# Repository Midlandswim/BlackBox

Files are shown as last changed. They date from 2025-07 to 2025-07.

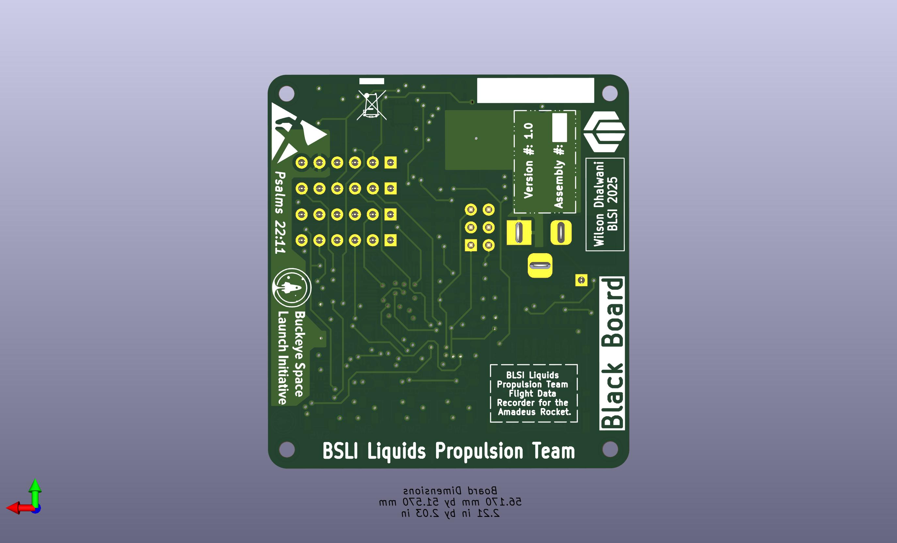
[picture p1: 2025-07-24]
Media/BlackBoxBLSIPCBBack.jpg

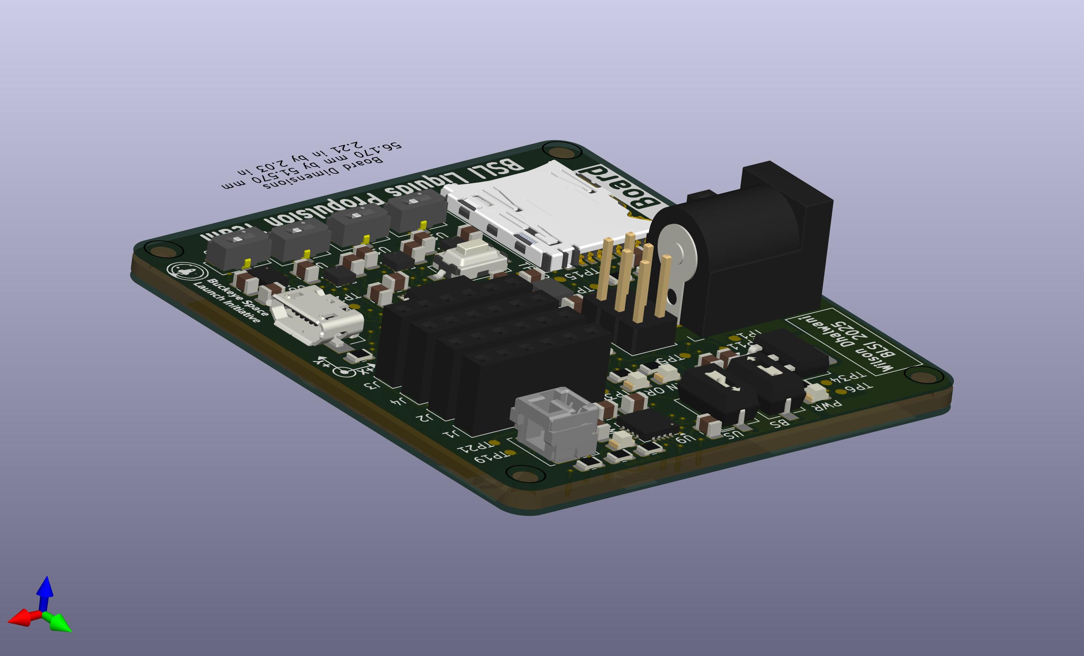
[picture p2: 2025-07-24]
Media/BlackBoxBLSIPCBSidejpg.jpg

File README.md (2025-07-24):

# BlackBox
BlackBox Flight Data Recorder

This is in partnership with Dhalwani Designs, which holds all rights, data, and procedures for this project and the related. This project was made for the Buckeye Space Launch Initiative Liquids Research Team. <br />

Researcher: Wilson Dhalwani <br />
Aides: Mr. Julian Hooks (OSU) <br />
Context: Dhalwani Designs Sanctioned Project and BSLI Liquids Project <br />
Project Name: The Blackbox <br />
Start Date: January 09, 2025 <br /> 

The following repository is for documenting and sharing my work in this research and competition project and its related fields of electrical and avionics engineering. This was also made to record my process of solving the issue at hand so that others can learn and build upon my work. Wanting to advance my experience and skills in avionics, as well as PCB design, I sought to join the Buckeye Space Launch Initiative, and specifically the Liquids Project Team (https://www.bsli.space/projects/liquids/). I quickly grasped concepts and joined the electronics/avionics subteam. Working closely with Mr. Julian Hooks, I have gained great experience, expertise, and knowledge in the field and its accompanying areas of study/research. Mr. Hooks has been an amazing team lead, mentor, and friend, and I hope to grow into half the leader and engineer he is. I was quickly assigned the task of creating the dedicated and versatile flight data recorder for the entire system of our up and coming rocket. For some context, this rocket will be a high powered rocket that aims to break the current collegiete apogee record. All custom designed, built, and manufactured, this rocket is composed of comepletly novel and innovative approaches to existing technology to advance the capabilities of the field but to also promote increased investment/interest into the related fields. Getting back to my individual role and contributions, I solely worked on the research, design, and development of this board, ensuring this critical component of the entire electronic as well as non-electronic systems would not only do its duty as our last resort, but still aid in achieving the overarching goals. One may notice key design choices throughout this board, as well as its expansive (and further expandable) capabilities. Ranging from dedicated and secure communication lines to extremely sensitive sensors, the BlackBox, as I have named it, will be a reliable yet hopefully unused aspect of this rocket. Aside from the more standard features such as event/data recording and reliable dedicated power systems, the processing and versatility of this system have been unmatched thus far (as compared to similar models in the collegeite field). A specialized enclosure was also designed to aid in protecting the board while also maximizing utility and accessibility during the implementation phase. This project has no end date as an innovation never ends, rather, continues until the idea is forgotten, and my hope is that this work can be the basis for future engineers who, too, find great excitement in innovation and design. <br />

Should you have any questions, comments, or just wish to reach out, email me at wilson.dhalwani@gmail.com !

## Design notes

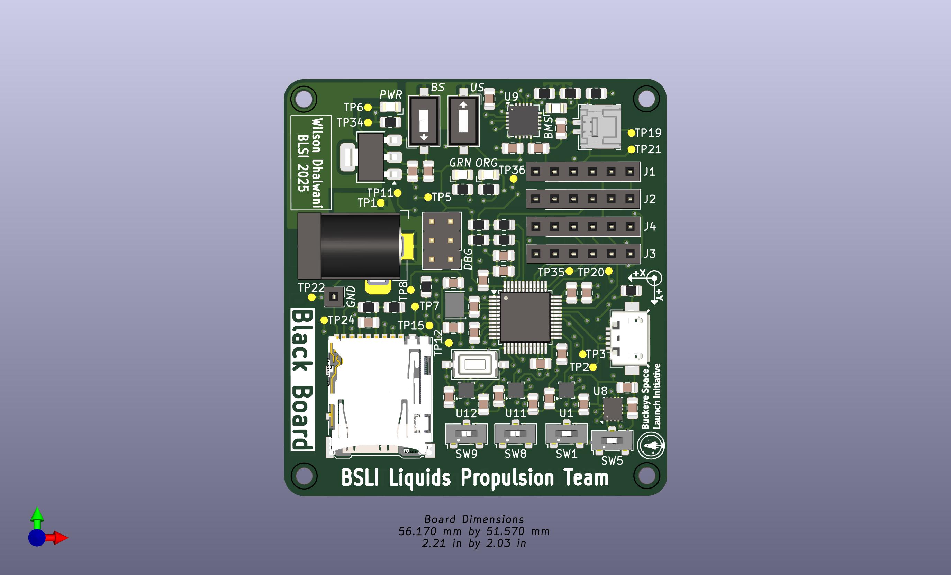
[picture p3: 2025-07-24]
Media/BlackBoxBLSIPCBFront.jpg

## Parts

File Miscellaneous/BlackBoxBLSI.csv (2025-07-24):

Id | Designator | Footprint | Quantity | Designation | Supplier and ref
1 | Y1 | Oscillator_SMD_EuroQuartz_XO32-4Pin_3.2x2.5mm | 1 | Crystal 32.768 kHz
2 | U8 | Bosch_LGA-14_3x2.5mm_P0.5mm | 1 | BMI323
3 | C35,C7,C6,C11,C10,C34,C42,C36,C8,C9 | C_0805_2012Metric | 10 | 100 nF
4 | TP5,TP34,TP12,TP6,TP11,TP7,TP36,TP8,TP20,TP22,TP35,TP24,TP2,TP1,TP21,TP19,TP15,TP3 | TestPoint_Pad_D1.0mm | 18 | TestPoint
5 | C13,C14 | C_0805_2012Metric | 2 | 0.1 uF
6 | PWR | LED_0805_2012Metric | 1 | BLULED
7 | U12,U1,U11 | ST_HLGA-10_2x2mm_P0.5mm_LayoutBorder3x2y | 3 | BMP390
8 | R19 | R_0805_2012Metric | 1 | 270 Ω
9 | C45,C43,C2,C46,C44,C1 | C_0805_2012Metric | 6 | 100nF
10 | H1,H2,H3,H4 | MountingHole_2.2mm_M2_ISO7380 | 4 | MountingHole_Pad
11 | SW5,SW1,SW8,SW9 | Nidec_Copal_CAS-120A | 4 | SW_SPDT
12 | U10 | SOT-223 | 1 | AMS1117-3.3
13 | LEDRES2,LEDRES1 | R_0805_2012Metric | 2 | 270Ω
14 | C5,C12,C41,C40,C37 | C_0805_2012Metric | 5 | 10 uF
15 | BS,US | SW_DIP_SPSTx01_Slide_6.7x4.1mm_W6.73mm_P2.54mm_LowProfile_JPin | 2 | SW_SPST
16 | C38,C39 | C_0805_2012Metric | 2 | 22 uF
17 | U9 | LFCSP-20-1EP_4x4mm_P0.5mm_EP2.6x2.6mm | 1 | ADP5063
18 | R7,R6 | R_0805_2012Metric | 2 | 4.7kΩ
19 | J1,J4,J2,J3 | PinSocket_1x06_P2.54mm_Vertical | 4 | Conn_01x06_Pin
20 | R20,R18 | R_0805_2012Metric | 2 | 10 kΩ
21 | GND | PinSocket_1x01_P2.54mm_Vertical | 1 | Conn_01x01_Pin
22 | R22,R23 | R_0805_2012Metric | 2 | 10k
23 | R9,R8 | R_0805_2012Metric | 2 | 1Ω
24 | J6 | BarrelJack_Horizontal | 1 | Barrel_Jack
25 | RSTCAP1 | R_0805_2012Metric | 1 | 0.1uF
26 | R21 | R_0805_2012Metric | 1 | 10kΩ
27 | C15 | C_0805_2012Metric | 1 | 3 pF
28 | BT1 | Molex_CLIK-Mate_502382-0270_1x02-1MP_P1.25mm_Vertical | 1 | 4.2V Batt
29 | BMS | LED_0805_2012Metric | 1 | REDLED
30 | J8 | USB_Micro-B_Amphenol_10104110_Horizontal | 1 | USB_B_Micro
31 | LEDRES3 | R_0805_2012Metric | 1 | 75Ω
32 | SW6 | SW_Tactile_SPST_NO_Straight_CK_PTS636Sx25SMTRLFS | 1 | SW_Push
33 | GRN | LED_0805_2012Metric | 1 | GREENLED
34 | J9 | microSD_HC_Hirose_DM3AT-SF-PEJM5 | 1 | Micro_SD_Card
35 | DBG | PinHeader_2x03_P2.54mm_Vertical | 1 | Conn_02x03_Counter_Clockwise
36 | U3 | LQFP-48_7x7mm_P0.5mm | 1 | STM32U575CIT6
37 | ORG | LED_0805_2012Metric | 1 | ORNGELED

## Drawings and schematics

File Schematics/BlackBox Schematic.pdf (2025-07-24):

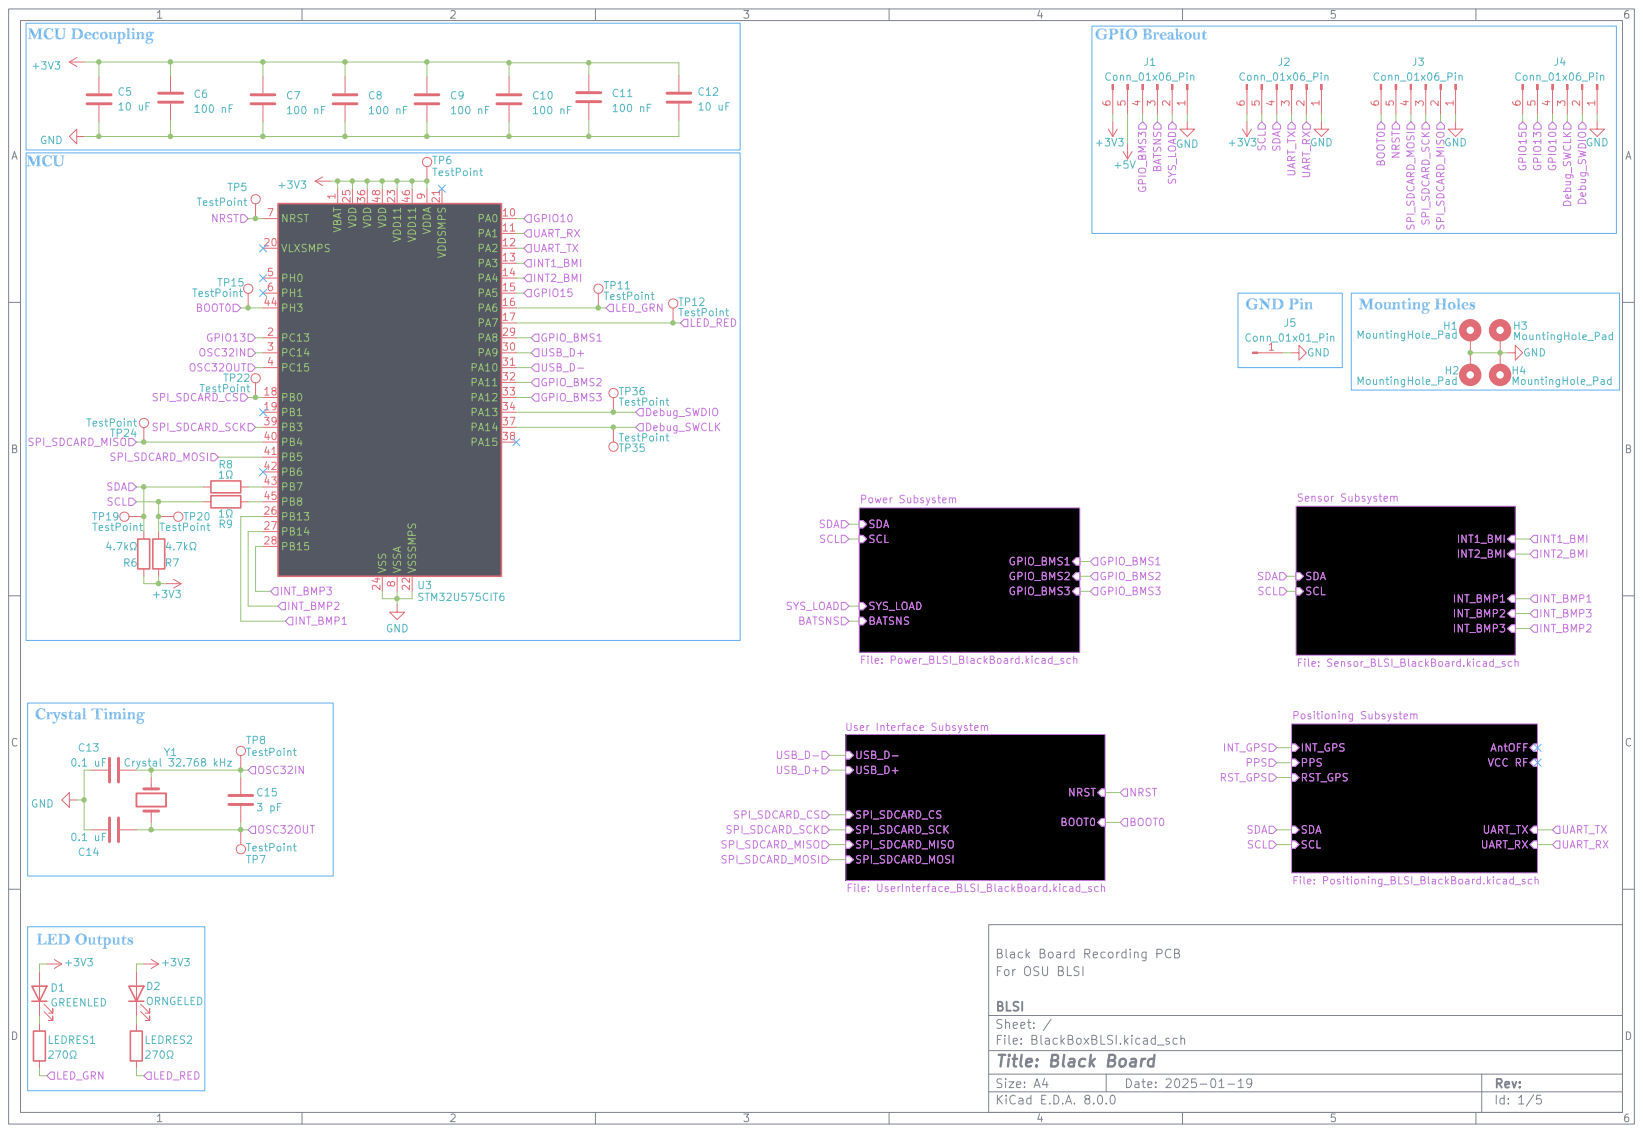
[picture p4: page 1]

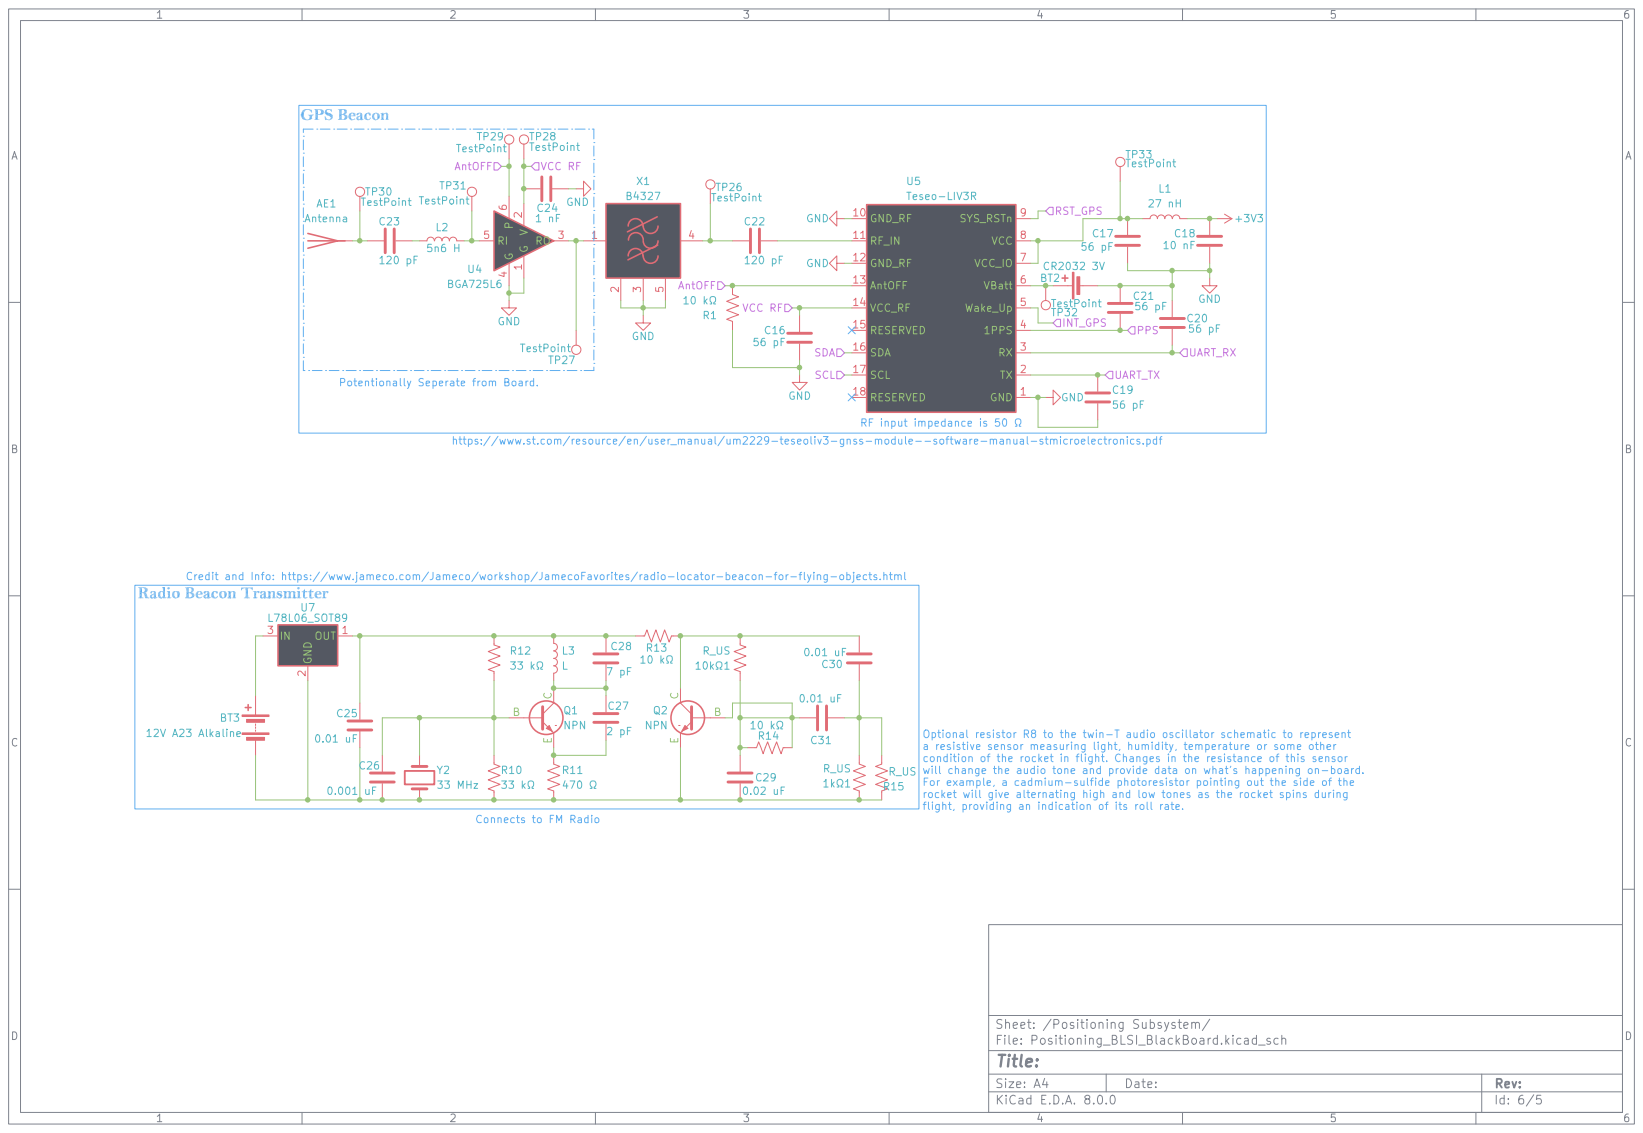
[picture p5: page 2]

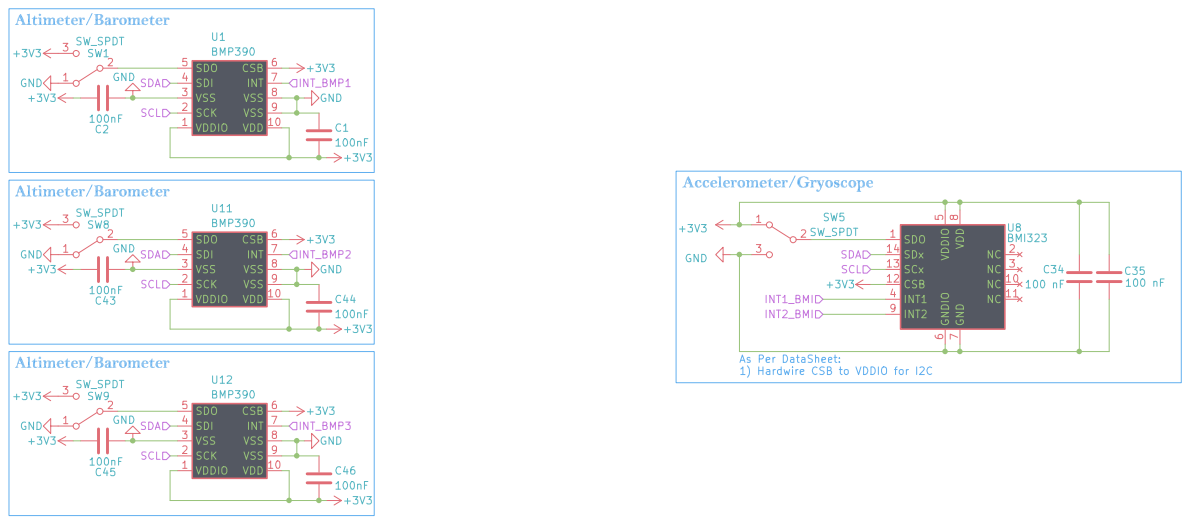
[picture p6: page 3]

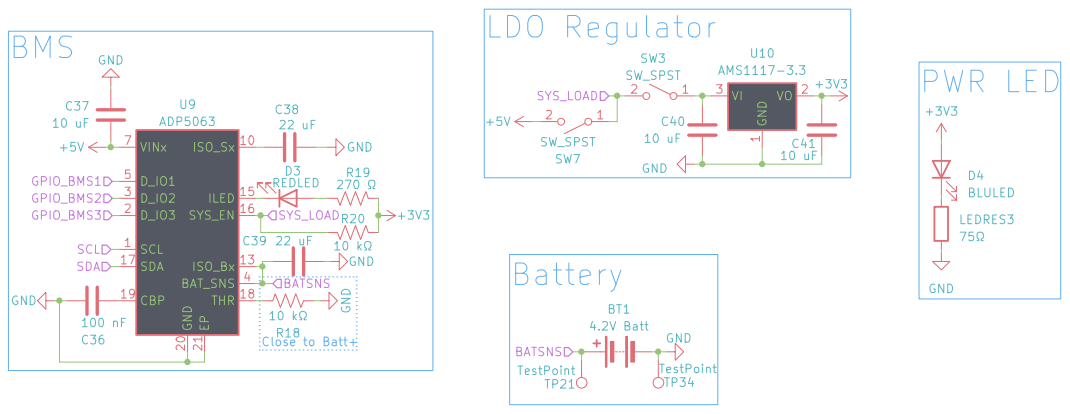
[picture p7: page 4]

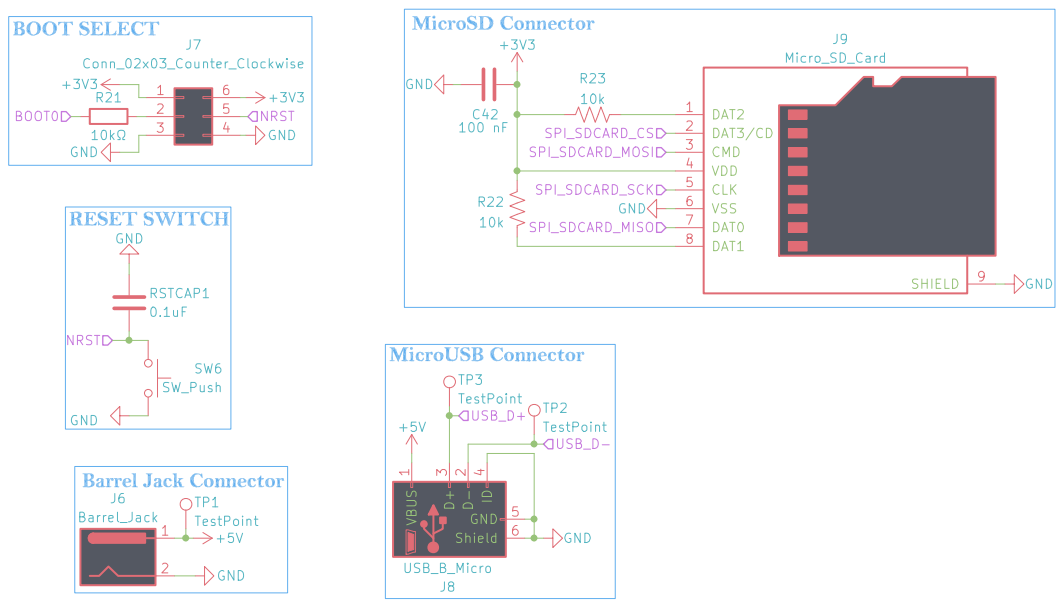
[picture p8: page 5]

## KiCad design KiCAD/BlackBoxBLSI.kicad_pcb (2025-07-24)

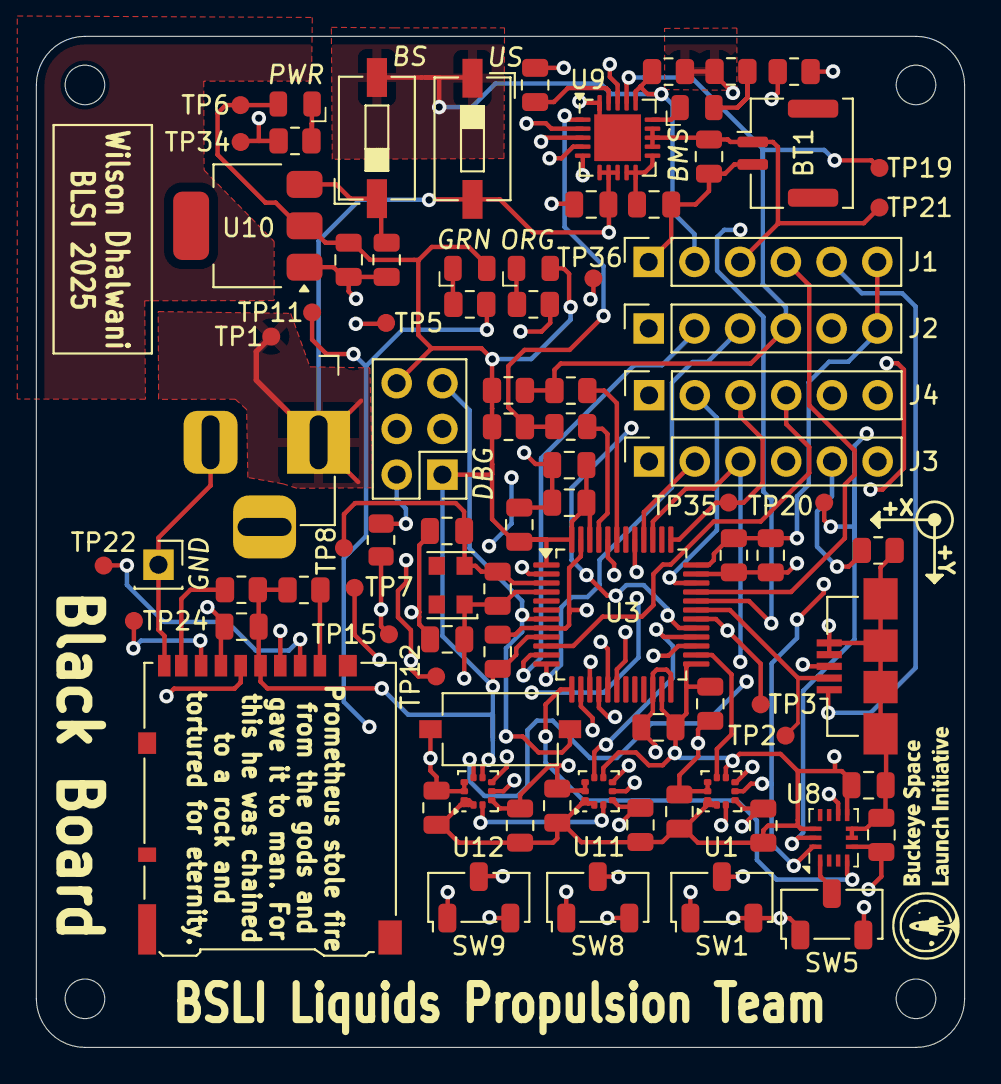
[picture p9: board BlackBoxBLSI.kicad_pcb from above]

Board: 4 copper layers, 51.6 x 56.2 mm, 91 parts (0 on the bottom side), 52 nets.

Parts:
BMS: REDLED; LED_0805_2012Metric
BS: SW_SPST; SW_DIP_SPSTx01_Slide_6.7x4.1mm_W6.73mm_P2.54mm_LowProfile_J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
BT1: 4.2V Batt; Molex_CLIK-Mate_502382-0270_1x02-1MP_P1.25mm_Vertical
C1, C2, C43, C44, C45, C46: 100nF; C_0805_2012Metric
C5, C12, C37, C40, C41: 10 uF; C_0805_2012Metric
C6, C7, C8, C9, C10, C11, C34, C35, C36, C42: 100 nF; C_0805_2012Metric
C13, C14: 0.1 uF; C_0805_2012Metric
C15: 3 pF; C_0805_2012Metric
C38, C39: 22 uF; C_0805_2012Metric
DBG: Conn_02x03_Counter_Clockwise; PinHeader_2x03_P2.54mm_Vertical
GND: Conn_01x01_Pin; PinSocket_1x01_P2.54mm_Vertical
GRN: GREENLED; LED_0805_2012Metric
H1, H2, H3, H4: MountingHole_Pad; MountingHole_2.2mm_M2_ISO7380
J1, J2, J3, J4: Conn_01x06_Pin; PinSocket_1x06_P2.54mm_Vertical
J6: Barrel_Jack; BarrelJack_Horizontal
J8: USB_B_Micro; USB_Micro-B_Amphenol_10104110_Horizontal
J9: Micro_SD_Card; microSD_HC_Hirose_DM3AT-SF-PEJM5
LEDRES1, LEDRES2: 270Ω; R_0805_2012Metric
LEDRES3: 75Ω; R_0805_2012Metric
ORG: ORNGELED; LED_0805_2012Metric
PWR: BLULED; LED_0805_2012Metric
R6, R7: 4.7kΩ; R_0805_2012Metric
R8, R9: 1Ω; R_0805_2012Metric
R18, R20: 10 kΩ; R_0805_2012Metric
R19: 270 Ω; R_0805_2012Metric
R21: 10kΩ; R_0805_2012Metric
R22, R23: 10k; R_0805_2012Metric
RSTCAP1: 0.1uF; R_0805_2012Metric
SW1, SW5, SW8, SW9: SW_SPDT; Nidec_Copal_CAS-120A
SW6: SW_Push; SW_Tactile_SPST_NO_Straight_CK_PTS636Sx25SMTRLFS
TP1, TP2, TP3, TP5, TP6, TP7, TP8, TP11, TP12, TP15, TP19, TP20, TP21, TP22, TP24, TP34, TP35, TP36: TestPoint; TestPoint_Pad_D1.0mm
U1, U11, U12: BMP390; ST_HLGA-10_2x2mm_P0.5mm_LayoutBorder3x2y
U3: STM32U575CIT6; LQFP-48_7x7mm_P0.5mm
U8: BMI323; Bosch_LGA-14_3x2.5mm_P0.5mm
U9: ADP5063; LFCSP-20-1EP_4x4mm_P0.5mm_EP2.6x2.6mm
U10: AMS1117-3.3; SOT-223
US: SW_SPST; SW_DIP_SPSTx01_Slide_6.7x4.1mm_W6.73mm_P2.54mm_LowProfile_J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
Y1: Crystal 32.768 kHz; Oscillator_SMD_EuroQuartz_XO32-4Pin_3.2x2.5mm

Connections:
+3V3: C1.2, C2.1, C5.1, C6.1, C7.1, C8.1, C9.1, C10.1, C11.1, C12.1, C34.1, C35.1, C41.1, C42.2, C43.1, C44.2, C45.1, C46.2, DBG.1, DBG.6, GRN.2 (A), J1.6, J2.6, J9.4 (VDD), ORG.2 (A), PWR.2 (A), R6.1, R7.2, R19.2, R20.2, R22.1, R23.1, SW1.3 (C), SW5.1 (A), SW8.3 (C), SW9.3 (C), TP6.1, U1.1 (VDDIO), U1.6 (CSB), U1.10 (VDD), U3.1 (VBAT), U3.9 (VDDA), U3.23 (VDD11), U3.25 (VDD), U3.36 (VDD), U3.46 (VDD11), U3.48 (VDD), U8.5 (VDDIO), U8.8 (VDD), U8.12 (CSB), U10.2 (VO), U11.1 (VDDIO), U11.6 (CSB), U11.10 (VDD), U12.1 (VDDIO), U12.6 (CSB), U12.10 (VDD)
+5V: C37.2, J1.5, J6.1, J8.1 (VBUS), TP1.1, U9.6 (VINx), U9.7 (VINx), U9.8 (VINx), US.2 (B)
/BATSNS: BT1.1 (+), C39.2, J1.3, TP21.1, U9.4 (BAT_SNS), U9.12 (ISO_Bx), U9.13 (ISO_Bx), U9.14 (ISO_Bx)
/BOOT0: J3.6, R21.2, TP15.1, U3.44 (PH3)
/Debug_SWCLK: J4.3, TP35.1, U3.37 (PA14)
/Debug_SWDIO: J4.2, TP36.1, U3.34 (PA13)
/GPIO10: J4.4, U3.10 (PA0)
/GPIO13: J4.5, U3.2 (PC13)
/GPIO15: J4.6, U3.15 (PA5)
/GPIO_BMS1: U3.29 (PA8), U9.5 (D_IO1)
/GPIO_BMS2: U3.32 (PA11), U9.3 (D_IO2)
/GPIO_BMS3: J1.4, U3.33 (PA12), U9.2 (D_IO3)
/INT1_BMI: U3.13 (PA3), U8.4 (INT1)
/INT2_BMI: U3.14 (PA4), U8.9 (INT2)
/INT_BMP1: U1.7 (INT), U3.26 (PB13)
/INT_BMP2: U3.27 (PB14), U12.7 (INT)
/INT_BMP3: U3.28 (PB15), U11.7 (INT)
/LED_GRN: LEDRES1.2, TP11.1, U3.16 (PA6)
/LED_RED: LEDRES2.2, TP12.1, U3.17 (PA7)
/NRST: DBG.5, J3.5, RSTCAP1.2, SW6.1, TP5.1, U3.7 (NRST)
/OSC32IN: C13.1, C15.1, TP8.1, U3.3 (PC14), Y1.2
/OSC32OUT: C14.2, C15.2, TP7.1, U3.4 (PC15), Y1.1
/SCL: J2.5, R7.1, R9.1, TP20.1, U1.2 (SCK), U8.13 (SCx), U9.1 (SCL), U11.2 (SCK), U12.2 (SCK)
/SDA: J2.4, R6.2, R8.1, TP19.1, U1.4 (SDI), U8.14 (SDx), U9.17 (SDA), U11.4 (SDI), U12.4 (SDI)
/SPI_SDCARD_CS: J9.2 (DAT3/CD), TP22.1, U3.18 (PB0)
/SPI_SDCARD_MISO: J3.2, J9.7 (DAT0), TP24.1, U3.40 (PB4)
/SPI_SDCARD_MOSI: J3.4, J9.3 (CMD), U3.41 (PB5)
/SPI_SDCARD_SCK: J3.3, J9.5 (CLK), U3.39 (PB3)
/SYS_LOAD: BS.2 (B), J1.2, R20.1, U9.16 (SYS_EN), US.1 (A)
/UART_RX: J2.2, U3.11 (PA1)
/UART_TX: J2.3, U3.12 (PA2)
/USB_D+: J8.3 (D+), TP3.1, U3.30 (PA9)
/USB_D-: J8.2 (D-), TP2.1, U3.31 (PA10)
GND: BT1.2 (-), C1.1, C2.2, C5.2, C6.2, C7.2, C8.2, C9.2, C10.2, C11.2, C12.2, C13.2, C14.1, C34.2, C35.2, C36.1, C37.1, C38.1, C39.1, C40.2, C41.2, C42.1, C43.2, C44.1, C45.2, C46.1, DBG.3, DBG.4, GND.1, J1.1, J2.1, J3.1, J4.1, J6.2, J8.4 (ID), J8.5 (GND), J8.6 (Shield), J9.6 (VSS), J9.9 (SHIELD), LEDRES3.2, R18.2, RSTCAP1.1, SW1.1 (A), SW5.3 (C), SW6.2, SW8.1 (A), SW9.1 (A), TP34.1, U1.3 (VSS), U1.8 (VSS), U1.9 (VSS), U3.8 (VSSA), U3.22 (VSSSMPS), U3.24 (VSS), U3.35 (VSS), U3.47 (VSS), U8.6 (GNDIO), U8.7 (GND), U9.20 (GND), U9.21 (EP), U10.1 (GND), U11.3 (VSS), U11.8 (VSS), U11.9 (VSS), U12.3 (VSS), U12.8 (VSS), U12.9 (VSS)
unnamed: C38.2, U9.9 (ISO_Sx), U9.10 (ISO_Sx), U9.11 (ISO_Sx)
unnamed: GRN.1 (K), LEDRES1.1
unnamed: LEDRES2.1, ORG.1 (K)
unnamed: BMS.2 (A), R19.1
unnamed: BMS.1 (K), U9.15 (ILED)
unnamed: LEDRES3.1, PWR.1 (K)
unnamed: DBG.2, R21.1
unnamed: J9.8 (DAT1), R22.2
unnamed: J9.1 (DAT2), R23.2
unnamed: SW1.2 (B), U1.5 (SDO)
unnamed: BS.1 (A), C40.1, U10.3 (VI)
unnamed: SW5.2 (B), U8.1 (SDO)
unnamed: SW8.2 (B), U11.5 (SDO)
unnamed: SW9.2 (B), U12.5 (SDO)
unnamed: R8.2, U3.43 (PB7)
unnamed: R9.2, U3.45 (PB8)
unnamed: C36.2, U9.19 (CBP)
unnamed: R18.1, U9.18 (THR)

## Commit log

2025-07-24 Relevant KiCAD Files
    All KiCAD files for now
    [BMI323BLSI_BB.kicad_sch, BMP390BLSI_BB.kicad_sch, BMS_BLSIBB.kicad_sch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]
2025-07-24 Complete KiCAD Schematic
    Schematic with Heirachy
2025-07-24 Miscellanous Stuff
    Netlist and BOM?
    [BlackBoxBLSI.csv]
2025-07-24 PCB Render Images
    Board Render Images from KiCAD
